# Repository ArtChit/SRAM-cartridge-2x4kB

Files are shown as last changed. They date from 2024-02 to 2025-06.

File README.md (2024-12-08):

# MSX SRAM cartridge 2x4kB

A MSX SRAM cartridge with battery backup. Compatible with Sony HBI-55 and Yamaha UDC-01 4kB cartridges (details: https://map.grauw.nl/resources/hbi55.php). Tested with Yamaha SFG-05 firmware. Based on i82C55A PPI and 8kB SRAM. Manual switching of lower/higher 4kB ("2-in-1").

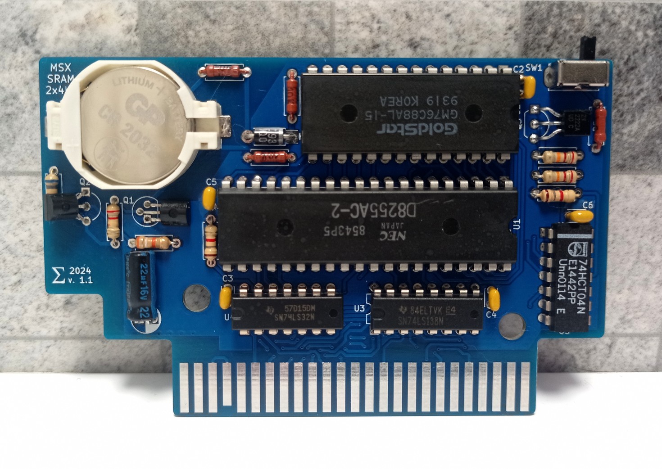
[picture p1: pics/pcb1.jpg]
Assembled

BOM:
- U1: 82C55A (PPI)
- U2: GoldStar (LG) GM76C88AL-15, SEC KM6264BL-10L(-12L) (8K x 8 Low Power CMOS SRAM, **100...150** ns). May work but not tested: NEC uPD4464-12L(-15L), Fujitsu MB8464A-10-W(-15-W).
- U3: 74LS138 (3-to-8 Decoder)
- U4: 74LS32 (OR gates)
- U5: 74LS04 (NOT gates)
- C1: 10uF/16V
- C2, C3, C4, C5, C6: 100nF
- Q1: 2N2907 (PNP BJT)
- Q2, Q3: 2N2222A (NPN BJT)
- D1: 11DQ04 (Schottky diode)
- BT1: CR2032 Battery Holder
- R1, R5, R6, R9: 10k
- R2: 6.8k
- R3: 39k
- R4, R8, R10: 22k
- R7, R11: 1.8k
- SW1: SPDT
  
A faster SRAM (e.g. UT6264B, 70 ns) works normally with relatively slow BASIC I/O commands but has a strange issue while working with SFG-05 software probably due strict timings.
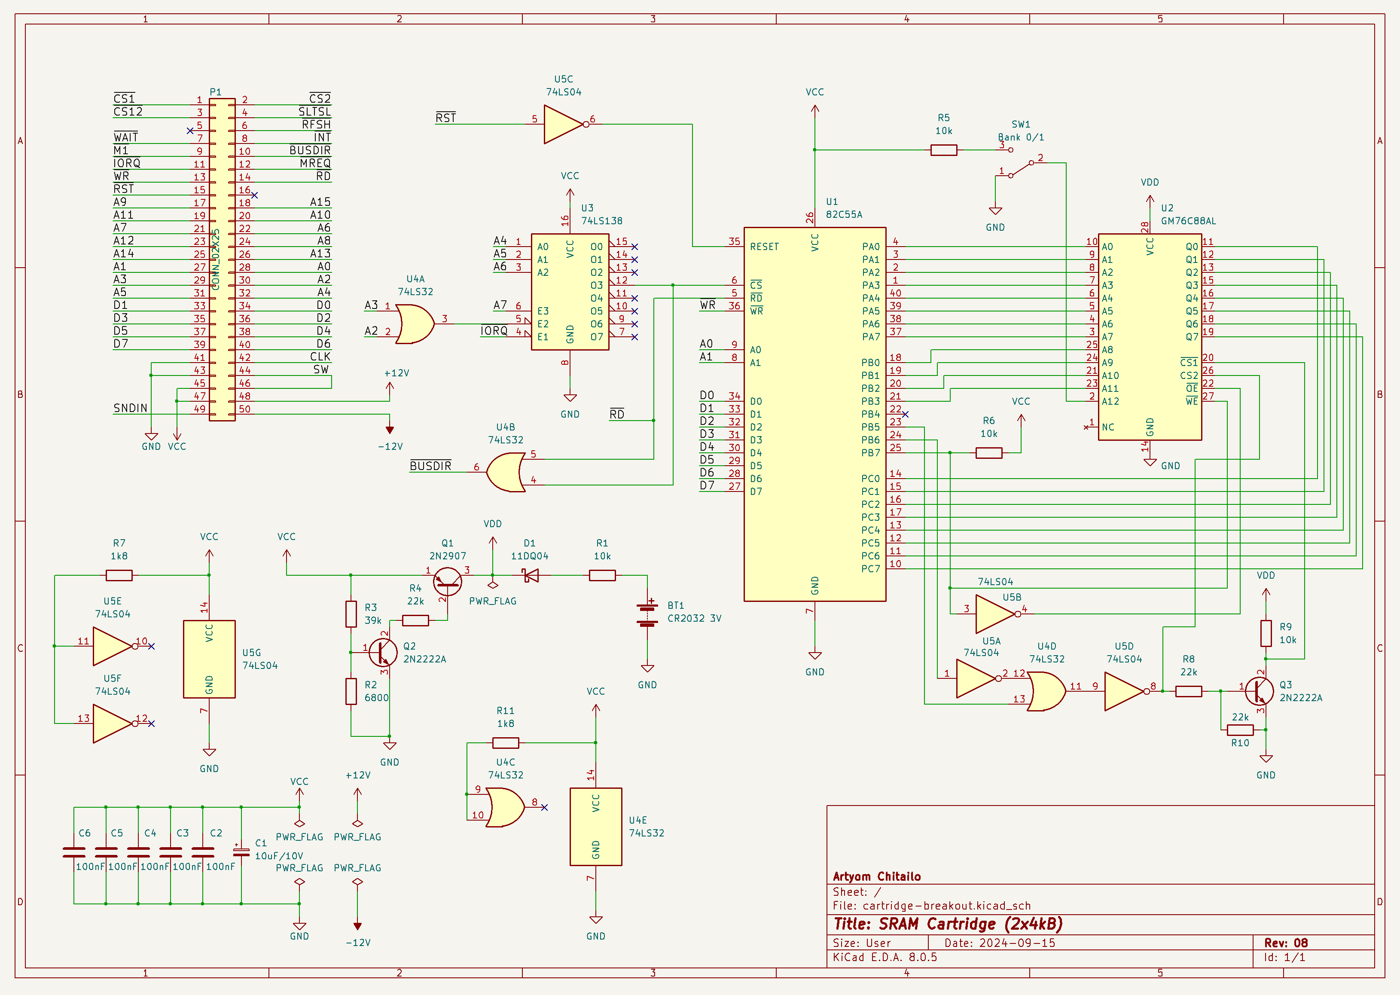
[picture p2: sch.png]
Schematics


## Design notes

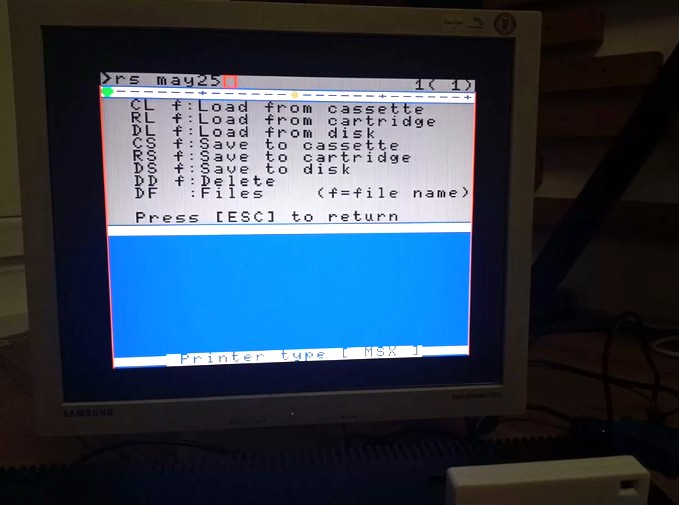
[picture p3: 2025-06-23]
pics/SRSave.jpg

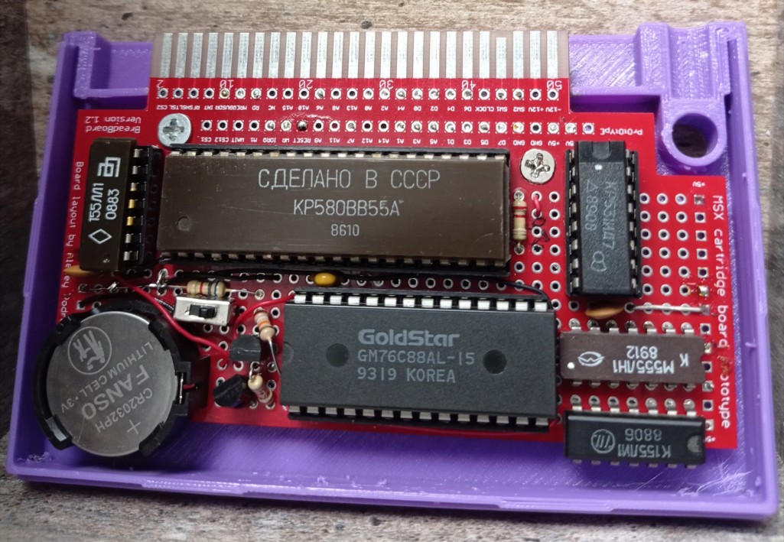
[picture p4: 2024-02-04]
pics/protob.jpg

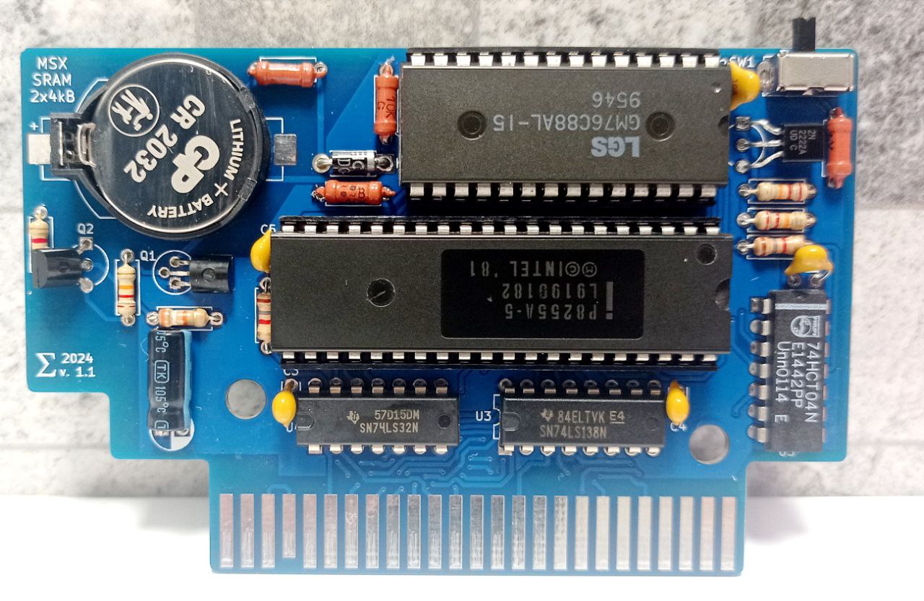
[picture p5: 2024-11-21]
pics/pcb1.1.jpg

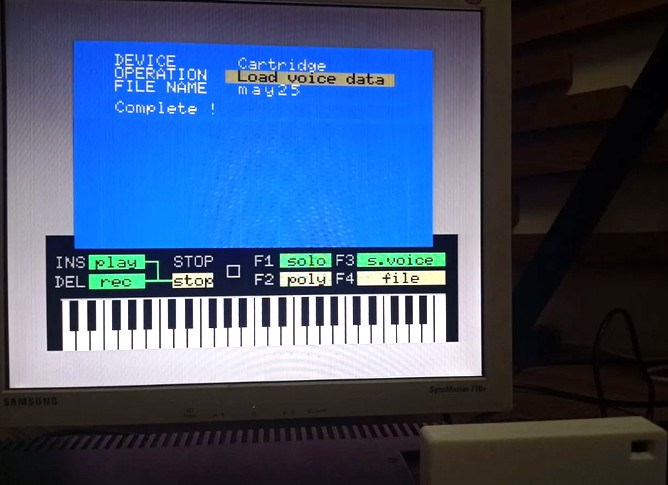
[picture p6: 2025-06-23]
pics/SRLoad.jpg

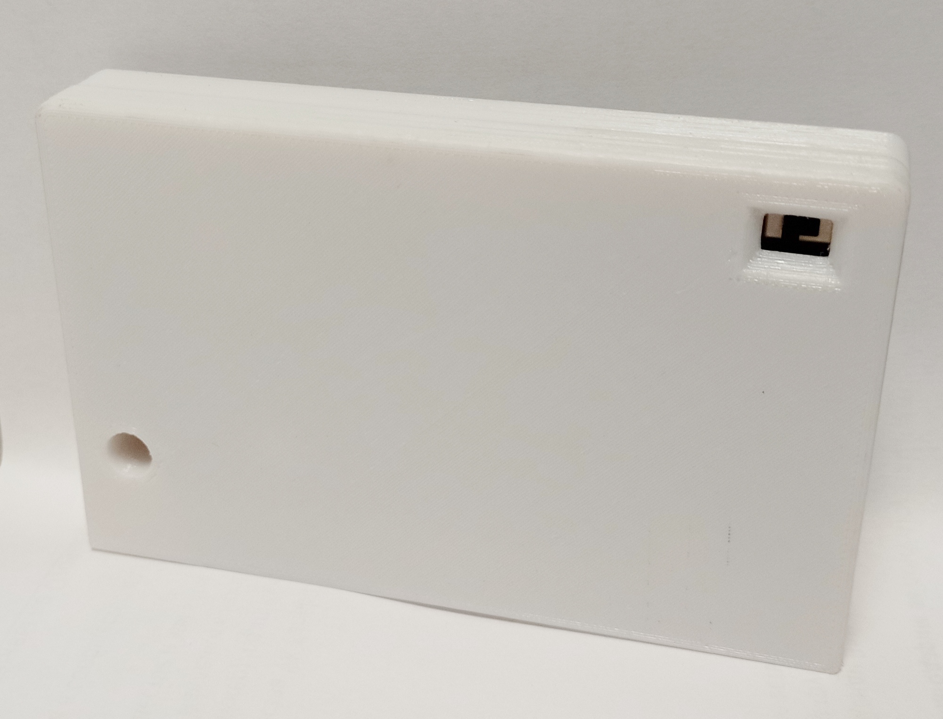
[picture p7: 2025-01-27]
Case/case_straightSW.jpg

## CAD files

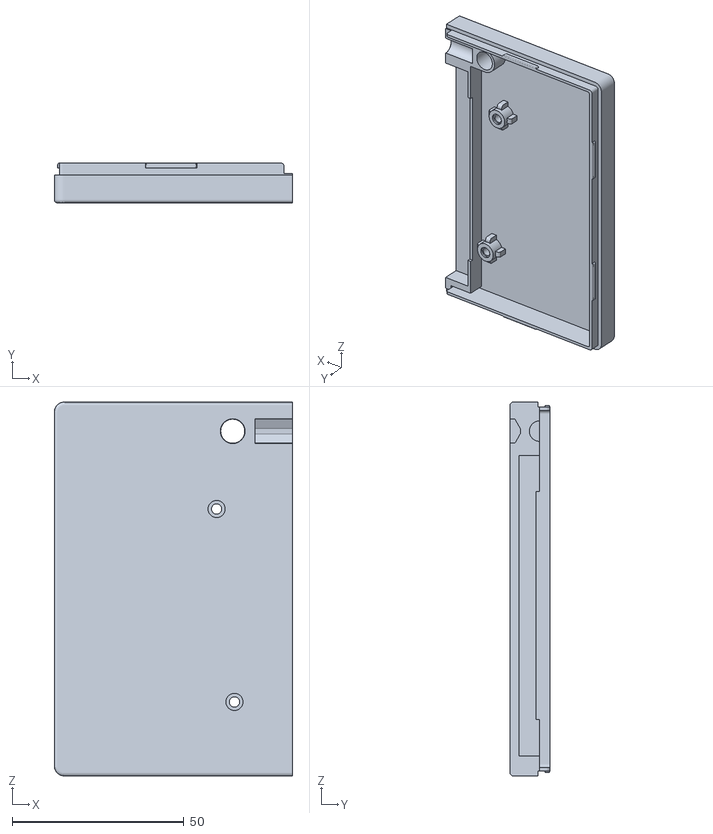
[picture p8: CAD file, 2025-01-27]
Case/SRAM11Bot.stl
69.5 x 11.6 x 109.0

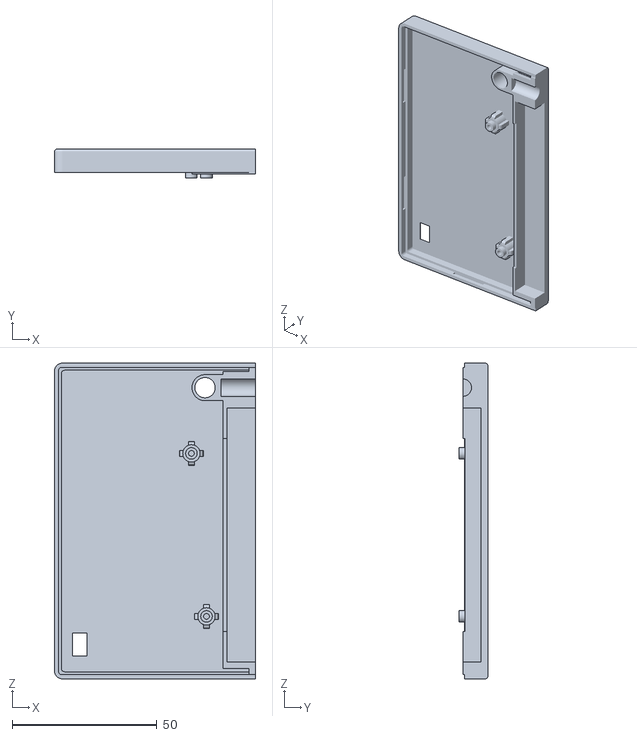
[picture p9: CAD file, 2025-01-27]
Case/SRAM11Top_straightSW.stl
69.5 x 9.95 x 109.0
